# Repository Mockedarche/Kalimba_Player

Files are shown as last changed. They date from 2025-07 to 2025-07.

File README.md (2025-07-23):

SPECIAL THANKS TO 

https://github.com/kevinmcaleer/pca9685_for_pico

AND

https://www.instructables.com/ESP32-Micro-SD-Card-Interface/

AND

https://github.com/0x3b29/Electric-Kalimba

This is a place for all my files related to my prototype of a ESP controlled Kalimba player

I've written drivers for different hardware but ultimately for a prototype it would likely take longer than the protoype. Both of these for the PCA9685 (with servo support) and that sdcard driver for micropython sped things up a lot.

This project is my prototype at a automatic kalimba player. I expect this over the next few months will get pushes all giving more support. Importantly this is a place for all files related to this project. Meaning CAD files, Notes, Python scripts, C/arduino code, microhydra code, etc. I ended up editing every STL provided by @olivier.berlin.
This project was fun but will likely be a bit more of a back burner project. Essentially this project is as follows 
1. Cardputer controls the kalimba player either directly saying what notes to play or it selects a song.
2. Kalimba player plays the tines as instructed by either the cardputer or the selected song

This is one of those projects were execution is the most important factor in the quality of the project. As such I came up with my own way of controlling, creating, and tuning each "pluck" as shown by the stls and all the code. Oliver wasn't my source of inspiration for the project and had been day dreaming about it for quite. Seeing their video showcased a really good stepping off point with the included cad files so thanks.

Things I'm happy with the project. 
1. Code it works reliably and in a determistic manner (different input combinations results in a intended behavior)
2. The cardputer controller software looks relatively nice and has a lot of really cool functionality such as playing songs, live playing (presses tell kalimba to play that tine), recording songs meaning you can play something live or in demo mode and save it wirelessly to the kalimba over local wifi, the kalimba player has an SD card so it can keep songs and there isn't any inherent limitation of length, speed, etc.
3. The kalimba player plays reliably and consistently meaning sounds are really constant and importantly the plucks piece that actually touches the tines are made from TPU meaning they will last an incredible amount of time.

Things that aren't satisfactory with this project
1. Code maturity is still really young. Often times the naive way was chosen and while nothing is really unoptimized im sure it could use less resources and be faster (especially connecting to the kalimba).
2. Sound quality of the kalimba player I can say with a lot of certainty that Oliver (third link) will admit that this doesn't sound as nice as a even decent person playing it. The plucks are one strength, sound different on pressing down vs lifting, and in my case the force required actually causes vibrations in the metal wire causing sound.

Things to do
1. Commect all of the code files to make picking the project up easier
2. Tune each pluck by changing the TPUs thickness and length so that keys are played in a more natural way.
3. Build some kind of case for the entire player that includes a sound chamber for the Kalimba
4. Create a desktop app that allows atleast selecting a song
5. Lube the servos to reduce their sound
6. find a way to dampen or completely cancel out the sound made by the metal wires on pluck

This is a back burner project im moving onto creating a 5 legged robot similar to https://youtu.be/IvK2I_ASXLo  

Photos
Kalimba controller (cardputer)


Kalimba Player
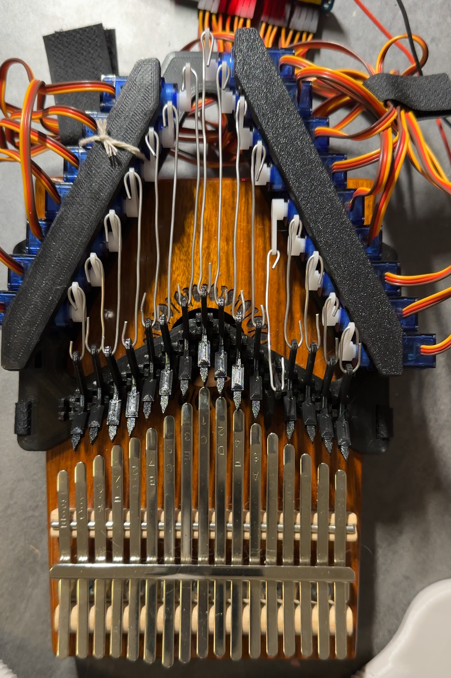
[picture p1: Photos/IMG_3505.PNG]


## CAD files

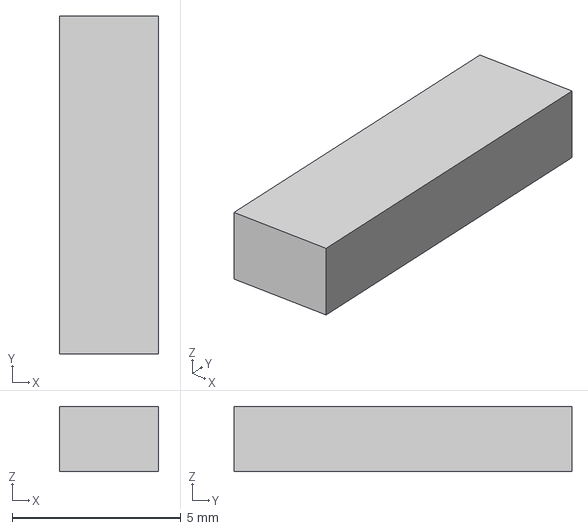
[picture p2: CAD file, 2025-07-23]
Cad files/PluckTPU v11.step
2.92 x 10.0 x 1.93 mm

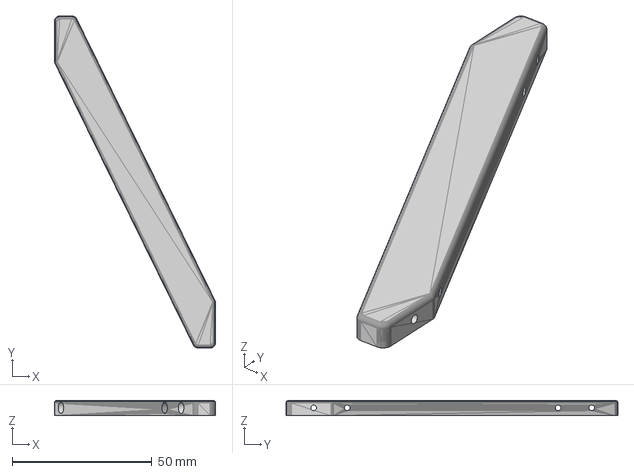
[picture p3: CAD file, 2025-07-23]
Cad files/Left arm (edited) v1.step
57.8 x 118.8 x 5.50 mm

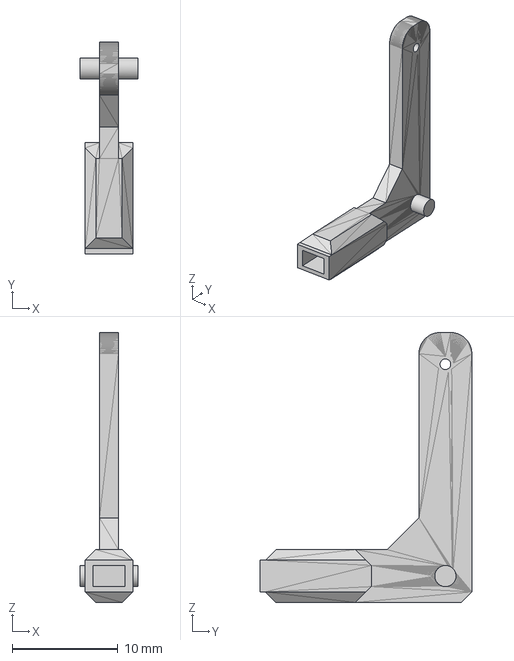
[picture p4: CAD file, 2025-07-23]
Cad files/pluck v14.step
5.50 x 20.0 x 25.5 mm

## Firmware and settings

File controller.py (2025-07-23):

import os
from machine import Pin, SoftSPI, I2C
from sdcard import SDCard
from pca9685 import PCA9685
from servo import Servos
import time
import network
import socket
import json
import _thread

requested_song = None


servos = None
servos_connected = [True, True, True, True, True, True, True, True,
                    True, True, True, True, True, True, True, True]

servos_angle = [0, 0, 0, 0, 0, 0, 0, 0, 0, 0, 0, 0, 0, 0, 0, 0, 0]

servo_number_side_switch = 9

internet_controllable_mode = True

lock = _thread.allocate_lock()

external_controlled_mode = False
main_controlled_mode = True

def external_mode_thread():
    global external_controlled_mode
    global main_controlled_mode
    global requested_song
    external_controlled_mode = False

    # Connect to Wi-Fi (if needed)
    ssid = 'WIFI SSID'
    password = 'WIFI PASSWORD'
    wlan = network.WLAN(network.STA_IF)
    wlan.active(True)
    wlan.connect(ssid, password)
    
    print("Connecting...", end="")
    while not wlan.isconnected():
        print(".", end="")
        time.sleep(0.5)
    
    print('Connected to Wi-Fi:', wlan.ifconfig())

    sock = socket.socket(socket.AF_INET, socket.SOCK_DGRAM)
    sock.bind(('0.0.0.0', 44444))

    while True:
        data,addr = sock.recvfrom(128)  # Buffer size is 128 bytes
        print("Received data:", data, "from", addr)

        if data.strip() == b"Connect":
            sock.sendto(b"Attempting Connection", addr)
            external_controlled_mode = True
            while main_controlled_mode:
                sock.sendto(b"Waiting on main thread to stop", addr)
                print("Waiting for main to take park...")
                time.sleep(2)
                
                
            sock.sendto(b"Finished", addr)
            
            while external_controlled_mode:
                print("External control mode active")
                data,addr = sock.recvfrom(128)  # Buffer size is 128 bytes
                try:
                    value = int(data.decode().strip())
                    print("Got an int:", value)
                    pluck_servo(value)
                except ValueError:
                    if data.strip() == b"Disconnect":
                        main_controlled_mode = True
                        external_controlled_mode = False
                        break
                    elif data.strip() == b"save_song":
                        print("here1")
                        sock.sendto(b"send", addr)
                        
                        print("here2")
                        data,addr = sock.recvfrom(1028)
                        print("here3")
                        song_data = json.loads(data.decode())

                        # Write to file on SD card
                        print("Type:", type(song_data))  # should say <class 'dict'>

                        print("saving song: " + str(song_data["metadata"]["title"]))
                        with open("/sd/songs/" + str(song_data["metadata"]["title"]) + ".json", "w") as f:
                            f.write(json.dumps(song_data))

                    elif data.strip() == b"get_songs":
                        print("Sending list of songs")
                        songs = os.listdir('/sd/songs')
                        sock.sendto(json.dumps(songs).encode(), addr)
                        
                    elif data.strip() == b"play_song":
                        print("Selecting song")
                        data, addr = sock.recvfrom(128)
                        requested_song = data.decode().strip()
                        print("Requested song:", requested_song)
                        # Check if the song exists
                        if requested_song in os.listdir('/sd/songs'):
                            print("Playing song:", requested_song)
                            sock.sendto(b"Song found, playing", addr)
                            # We want the main thread to play the song
                            main_controlled_mode = True
                            external_controlled_mode = False
                            break

                        else:
                            print("Song not found:", requested_song)
                            sock.sendto(b"Song not found", addr)
                            
                    elif data.strip() == b"Clear_song":
                        requested_song = None
                        
                   
                



# =============================================# 
# Song Player
# =============================================
def song_player(song_name):
    # read in the song in json format from /sd/songs/
    try:
        with open("/sd/songs/" + str(song_name), "r") as f:
            print("File exists!")
            song_data = json.loads(f.read())    

            print("Playing song:", song_data["metadata"]["title"])
            for note in song_data["notes"]:
                pluck_servo(int(note["tine"]))
                time.sleep_ms(note["gap_duration"])
    except OSError:
        print("File not found.")


        
# =============================================
# SD Card Setup
# =============================================
def setup_sd_card():
    # Pin assignment for SD card (using hardware SPI)
    # MISO -> GPIO 19
    # MOSI -> GPIO 23
    # SCK  -> GPIO 18
    # CS   -> GPIO 5
    spisd = SoftSPI(-1, miso=Pin(19), mosi=Pin(23), sck=Pin(18))
    sd = SDCard(spisd, Pin(5))
    
    # Mount filesystem
    vfs = os.VfsFat(sd)
    os.mount(vfs, '/sd')
    print('SD Card mounted')
    print('SD Card contains:', os.listdir('/sd'))
    return sd

# =============================================
# Servo Controller Setup
# =============================================
def setup_servos():
    # I2C setup for PCA9685 servo controller
    i2c = I2C(sda=Pin(21), scl=Pin(22))
    pca = PCA9685(i2c=i2c)
    global servos
    servos = Servos(i2c=i2c)
    n = 16
    
    # Initialize all servos to starting position
    # Pluck all tines (move up)
    for i in range(n):
        if servos_connected[i]:
            if i < 9:
                servos_angle[i] = 110
                servos.position(index=i, degrees=110)
            else:
                servos_angle[i] = 110
                servos.position(index=i, degrees=70)
            time.sleep(0.5)
    
    print('Servos initialized')

def pluck_servo(index_to_pluck):
    if index_to_pluck < 9:
        if servos_angle[index_to_pluck] == 0:
            servos_angle[index_to_pluck] = 110
            servos.position(index=index_to_pluck, degrees=110)
        else:
            servos_angle[index_to_pluck] = 0
            servos.position(index=index_to_pluck, degrees=0)
    else:
        if servos_angle[index_to_pluck] == 180:
            servos_angle[index_to_pluck] = 70
            servos.position(index=index_to_pluck, degrees=70)
        else:
            servos_angle[index_to_pluck] = 180
            servos.position(index=index_to_pluck, degrees=180)






# =============================================
# Main Application
# =============================================
def main():
    # Initialize hardware
    #sd = setup_sd_card()
    global main_controlled_mode
    global external_controlled_mode
    global servos
    global requested_song
    
    setup_servos()
    sd = setup_sd_card()

    _thread.start_new_thread(external_mode_thread, ())

    while True:

        while not external_controlled_mode:
            if requested_song is None:
                print("Waiting for external control mode...")
                time.sleep(1)
            else:
                print(requested_song)
                song_player(requested_song)
                time.sleep(5)

        if external_controlled_mode:
            main_controlled_mode = False
            while not main_controlled_mode:
                print("Waiting for external mode to finish...")
                time.sleep(1)





if __name__ == '__main__':
    main()
    print("EXITING")

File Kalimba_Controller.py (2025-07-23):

import time
from lib import display, userinput
from lib.hydra import config
import socket
import network
from array import array
from lib.hydra import beeper
import os
from lib.sdcard import mhsdcard
import sys
import math
import json
 
"""
NOTES

Colors are just a 16 bit color aka RGB565 meaning whatever passed just becomes this. For fine grain control use a binary representation like 0b1111100000000000

Must call DISPLAY.show() to actually have changes applied. Think of it as VRR where the display is only updated when a frame is complete meaning we can set up an entire frame
whatever time span we want since the frame buffer is only pushed when we call. 

"""
 
sd = mhsdcard.SDCard()
sd.mount()
 
# ~~~~~~~~~~~~~~~~~~~~~~~~~~~~~~~~~~~ _CONSTANTS: ~~~~~~~~~~~~~~~~~~~~~~~~~~~~~~~~~~~~~~
_MH_DISPLAY_HEIGHT = const(135)
_MH_DISPLAY_WIDTH = const(240)
_DISPLAY_WIDTH_HALF = const(_MH_DISPLAY_WIDTH // 2)

_CHAR_WIDTH = const(8)
_CHAR_WIDTH_HALF = const(_CHAR_WIDTH // 2)


# ~~~~~~~~~~~~~~~~~~~~~~~~~~~~~~~~~ GLOBAL_OBJECTS: ~~~~~~~~~~~~~~~~~~~~~~~~~~~~~~~~~~~~
# init object for accessing display
DISPLAY = display.Display(use_tiny_buf=True)

# object for accessing microhydra config (Delete if unneeded)
CONFIG = config.Config()

# object for reading keypresses (or other user input)
INPUT = userinput.UserInput()

demo_layout_mode = False
demo_mode = True

# Used to clear screen
CONFIG.palette[0] = 0
# Text notes
CONFIG.palette[1] = 65472
# Recording logo
CONFIG.palette[2] = 63488
# Top Label background
CONFIG.palette[3] = 12292
# Bottom Label background
CONFIG.palette[4] = 10565
# White text
CONFIG.palette[5] = 65535
# Text keys
CONFIG.palette[6] = 12222
# Play lines
CONFIG.palette[7] = 23211
# Green for connected
CONFIG.palette[8] = 2016
# Main menu style border
CONFIG.palette[9] = 10989

"""
CONFIG.palette[3] =
CONFIG.palette[3] =
CONFIG.palette[3] =
CONFIG.palette[3] =
CONFIG.palette[3] =
CONFIG.palette[3] =
CONFIG.palette[3] =
CONFIG.palette[3] =
CONFIG.palette[3] =
CONFIG.palette[3] =
CONFIG.palette[3] =
CONFIG.palette[3] =
"""
how_many_notes_to_show = 11
notes_played = [''] * how_many_notes_to_show
keys_played = [''] * how_many_notes_to_show
reload_overlay_flag = False
update_play_graphics = True
connected_flag = False

sock = None


# ~~~~~~~~~~~~~~~~~~~~~~~~~~~~~~~~~~~~~ FUNCTIONS: ~~~~~~~~~~~~~~~~~~~~~~~~~~~~~~~~~~~~
def clear_frame():
    # clear framebuffer
    DISPLAY.fill(CONFIG.palette[0])


def player(sock, address, demo_mode):
    global reload_overlay_flag
    global update_play_graphics
    recording_notes_played = []
    reload_overlay_flag = True
    last_blinked_recording_logo = time.ticks_ms()
    recording_blink_flag = False
    recording_flag = False
    play_sound_flag = True
    
    
    time_to_play_ms = 500
    
    songs_path = "/sd/Kalimba/Songs"

    print(os.listdir(songs_path))

    
    if play_sound_flag:
        for i in range(17):

            play_sound(i, 50)
            time.sleep_ms(51)
            
    
    
    while True:
        player_layout(play_sound_flag)
        keys = INPUT.get_new_keys()
        # if there are keys, convert them to a string, and store for display
        if keys:
            
            print(keys)
            
            if "1" in keys:
                packet = "0"
                if not demo_mode:
                    sock.sendto(packet, address)
                    
                if recording_flag:
                    recording_notes_played.append(("0", time.ticks_ms()))
                if play_sound_flag:
                    play_sound(0, time_to_play_ms)
                
                notes_played[0] = "1"
                keys_played[0] = "1"
                update_play_graphics = True
                
            elif "2" in keys:
                packet = "1"
                if not demo_mode:
                    sock.sendto(packet, address)
                    
                if recording_flag:
                    recording_notes_played.append(("1", time.ticks_ms()))
                if play_sound_flag:
                    play_sound(1, time_to_play_ms)
                    
                notes_played[0] = "2"
                keys_played[0] = "2"
                update_play_graphics = True

                
            elif "3" in keys:
                packet = "2"
                if not demo_mode:
                    sock.sendto(packet, address)
                    
                if recording_flag:
                    recording_notes_played.append(("2", time.ticks_ms()))
                if play_sound_flag:
                    play_sound(3, time_to_play_ms)
                
                notes_played[0] = "4"
                keys_played[0] = "3"
                update_play_graphics = True

                
            elif "4" in keys:
                packet = "3"
                if not demo_mode:
                    sock.sendto(packet, address)
                    
                if recording_flag:
                    recording_notes_played.append(("3", time.ticks_ms()))
                if play_sound_flag:
                    play_sound(5, time_to_play_ms)
                
                notes_played[0] = "6"
                keys_played[0] = "4"
                update_play_graphics = True

                
            elif "5" in keys:
                packet = "4"
                if not demo_mode:
                    sock.sendto(packet, address)
                    
                if recording_flag:
                    recording_notes_played.append(("4", time.ticks_ms()))
                if play_sound_flag:
                    play_sound(7, time_to_play_ms)
                
                notes_played[0] = "1'"
                keys_played[0] = "5"
                update_play_graphics = True

                
            elif "7" in keys:
                packet = "9"
                if not demo_mode:
                    sock.sendto(packet, address)
                    
                if recording_flag:
                    recording_notes_played.append(("9", time.ticks_ms()))
                if play_sound_flag:
                    play_sound(2, time_to_play_ms)
                
                notes_played[0] = "3"
                keys_played[0] = "7"
                update_play_graphics = True

                
            elif "8" in keys:
                packet = "10"
                if not demo_mode:
                    sock.sendto(packet, address)
                    
                if recording_flag:
                    recording_notes_played.append(("10", time.ticks_ms()))
                if play_sound_flag:
                    play_sound(4, time_to_play_ms)
                
                notes_played[0] = "5"
                keys_played[0] = "8"
                update_play_graphics = True
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

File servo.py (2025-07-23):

# servo.py
# Kevin McAleer
# March 2021
from pca9685 import PCA9685
import math


class Servos:
    def __init__(self, i2c, address=0x40, freq=50, min_us=600, max_us=2400,
                 degrees=180):
        self.period = 1000000 / freq
        self.min_duty = self._us2duty(min_us)
        self.max_duty = self._us2duty(max_us)
        self.degrees = degrees
        self.freq = freq
        self.pca9685 = PCA9685(i2c, address)
        self.pca9685.freq(freq)

    def _us2duty(self, value):
        return int(4095 * value / self.period)

    def position(self, index, degrees=None, radians=None, us=None, duty=None):
        span = self.max_duty - self.min_duty
        if degrees is not None:
            duty = self.min_duty + span * degrees / self.degrees
        elif radians is not None:
            duty = self.min_duty + span * radians / math.radians(self.degrees)
        elif us is not None:
            duty = self._us2duty(us)
        elif duty is not None:
            pass
        else:
            return self.pca9685.duty(index)
        duty = min(self.max_duty, max(self.min_duty, int(duty)))
        self.pca9685.duty(index, duty)

    def release(self, index):
        self.pca9685.duty(index, 0)
